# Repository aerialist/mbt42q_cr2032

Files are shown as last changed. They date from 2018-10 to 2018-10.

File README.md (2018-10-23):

# MDBT42Q BLE module breakout board

This is a breakout board for MDBT42Q module, a nRF52 based BLE.
https://www.seeedstudio.com/MDBT42Q-nRF52832-based-BLE-module-p-2736.html
http://www.raytac.com/product/ins.php?index_id=31

Schematics is largely copied from and inspired by Adafruit Feather nRF52 Bluefruit LE
https://www.adafruit.com/product/3406
https://learn.adafruit.com/bluefruit-nrf52-feather-learning-guide/introduction

and Redbear BLE Nano v2
https://redbear.cc/product/ble/ble-nano-2-soldered.html
https://github.com/redbear/nRF5x/tree/master/nRF52832

so that Arduino BSP developed by Adafruit or Redbear could be used as well as SDK from Nordic.
(Personally I'd recommend to go with Adafruit now that Redbear joined Particle)

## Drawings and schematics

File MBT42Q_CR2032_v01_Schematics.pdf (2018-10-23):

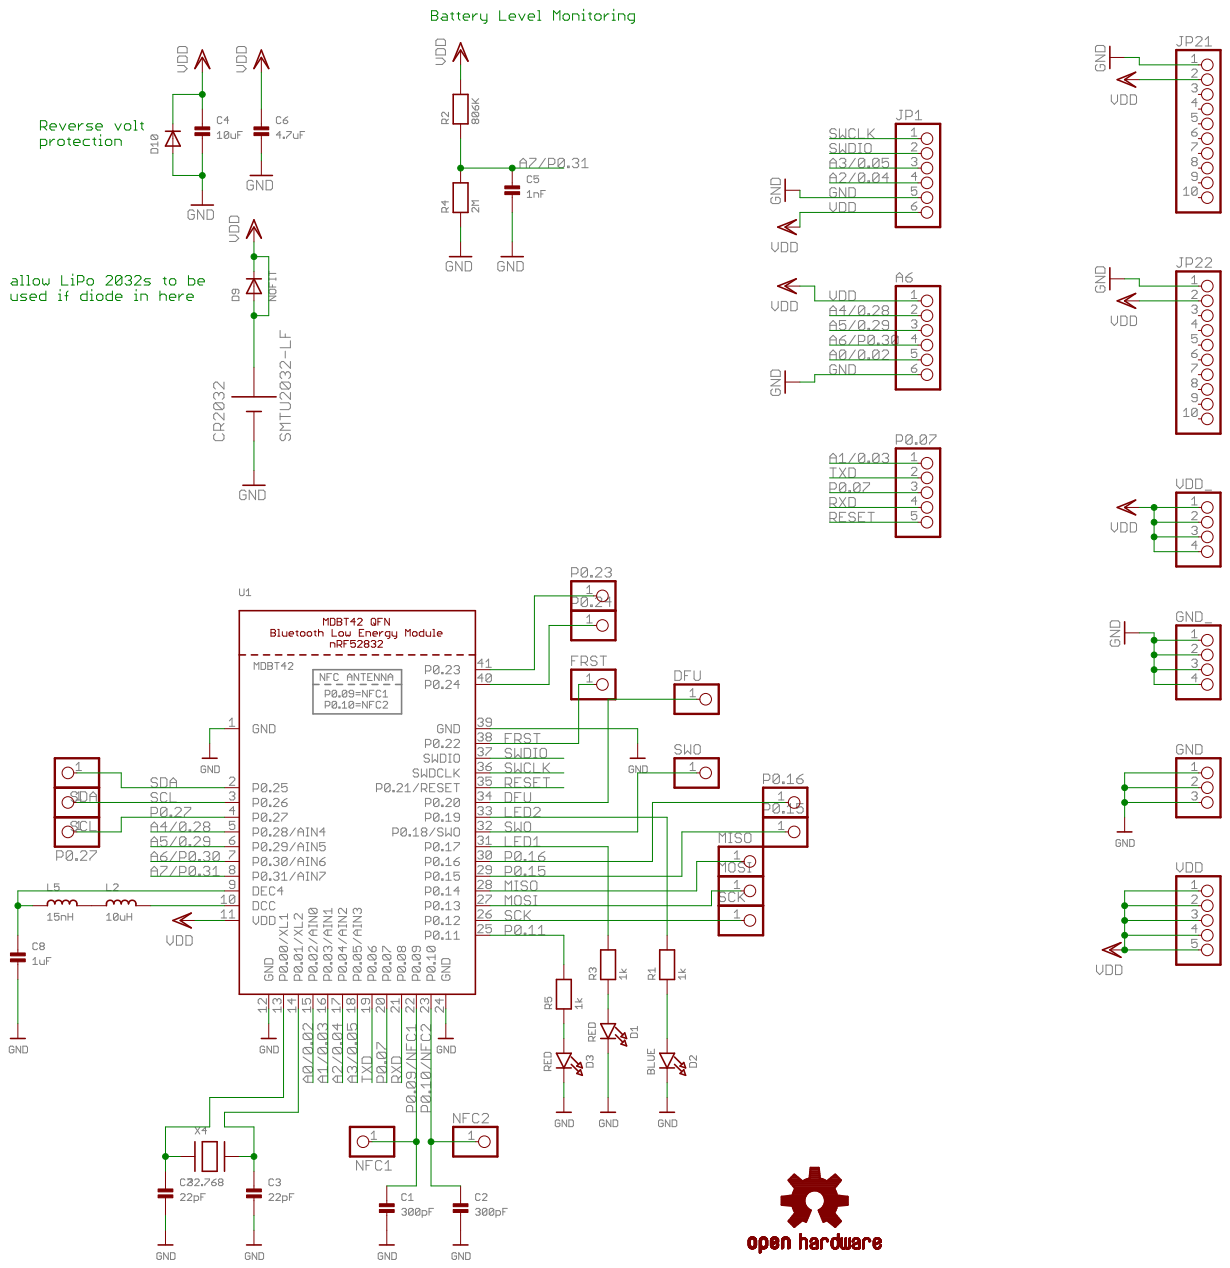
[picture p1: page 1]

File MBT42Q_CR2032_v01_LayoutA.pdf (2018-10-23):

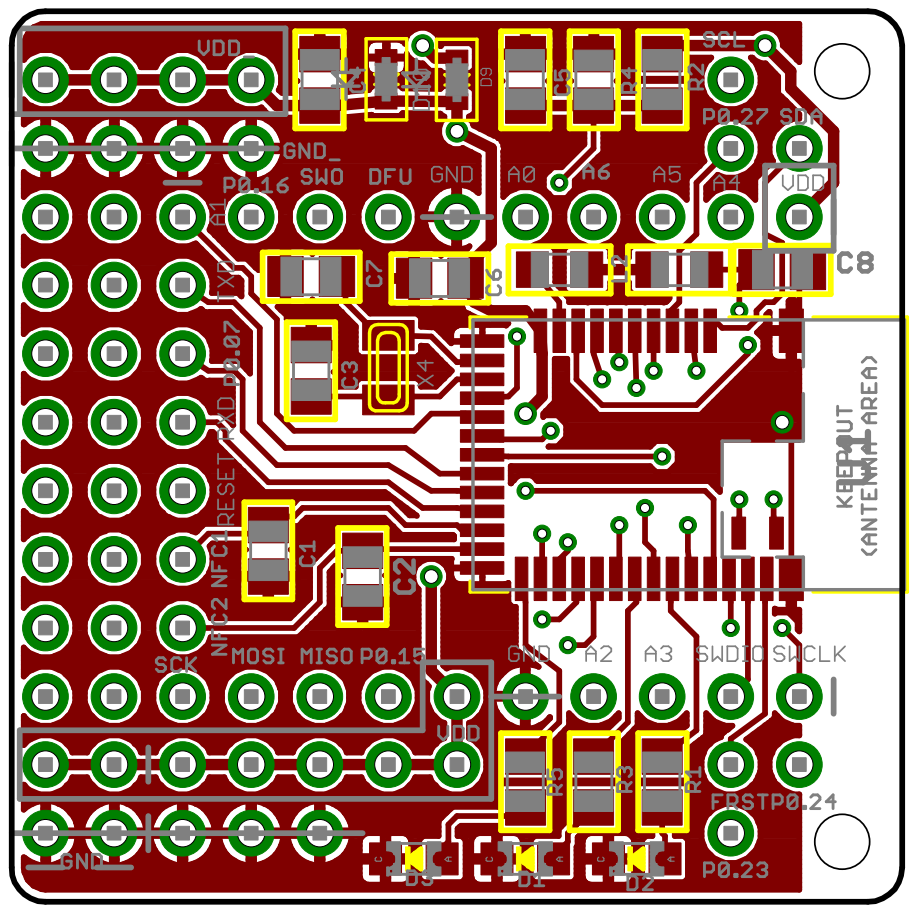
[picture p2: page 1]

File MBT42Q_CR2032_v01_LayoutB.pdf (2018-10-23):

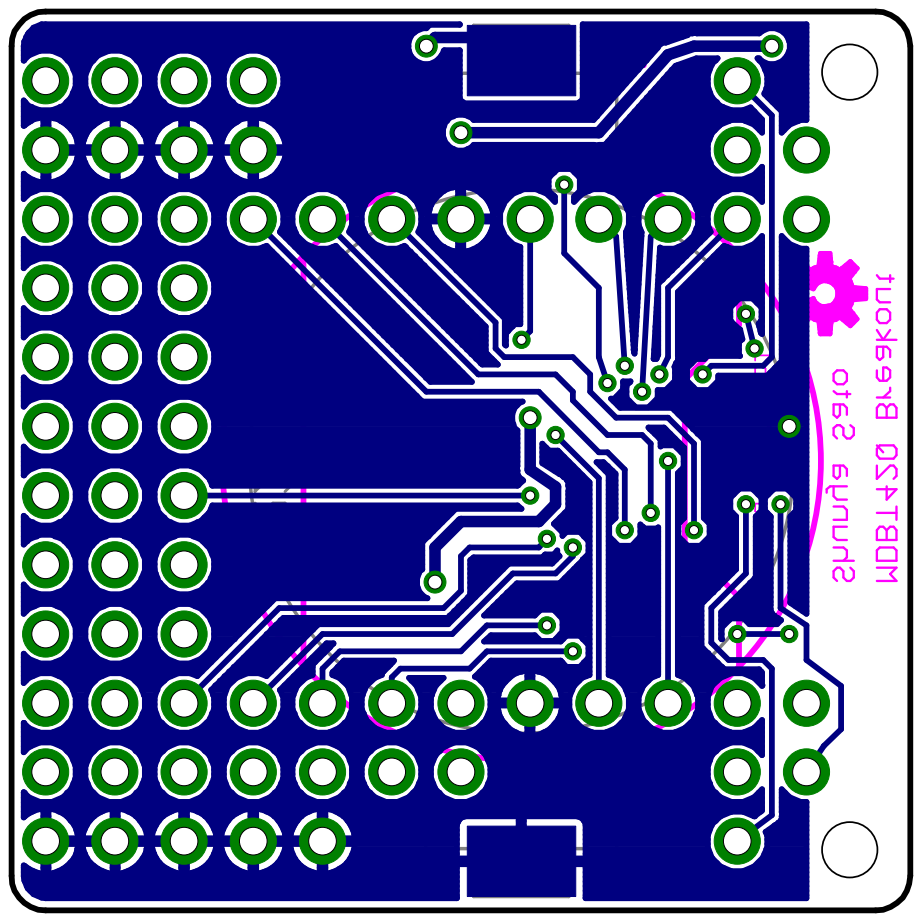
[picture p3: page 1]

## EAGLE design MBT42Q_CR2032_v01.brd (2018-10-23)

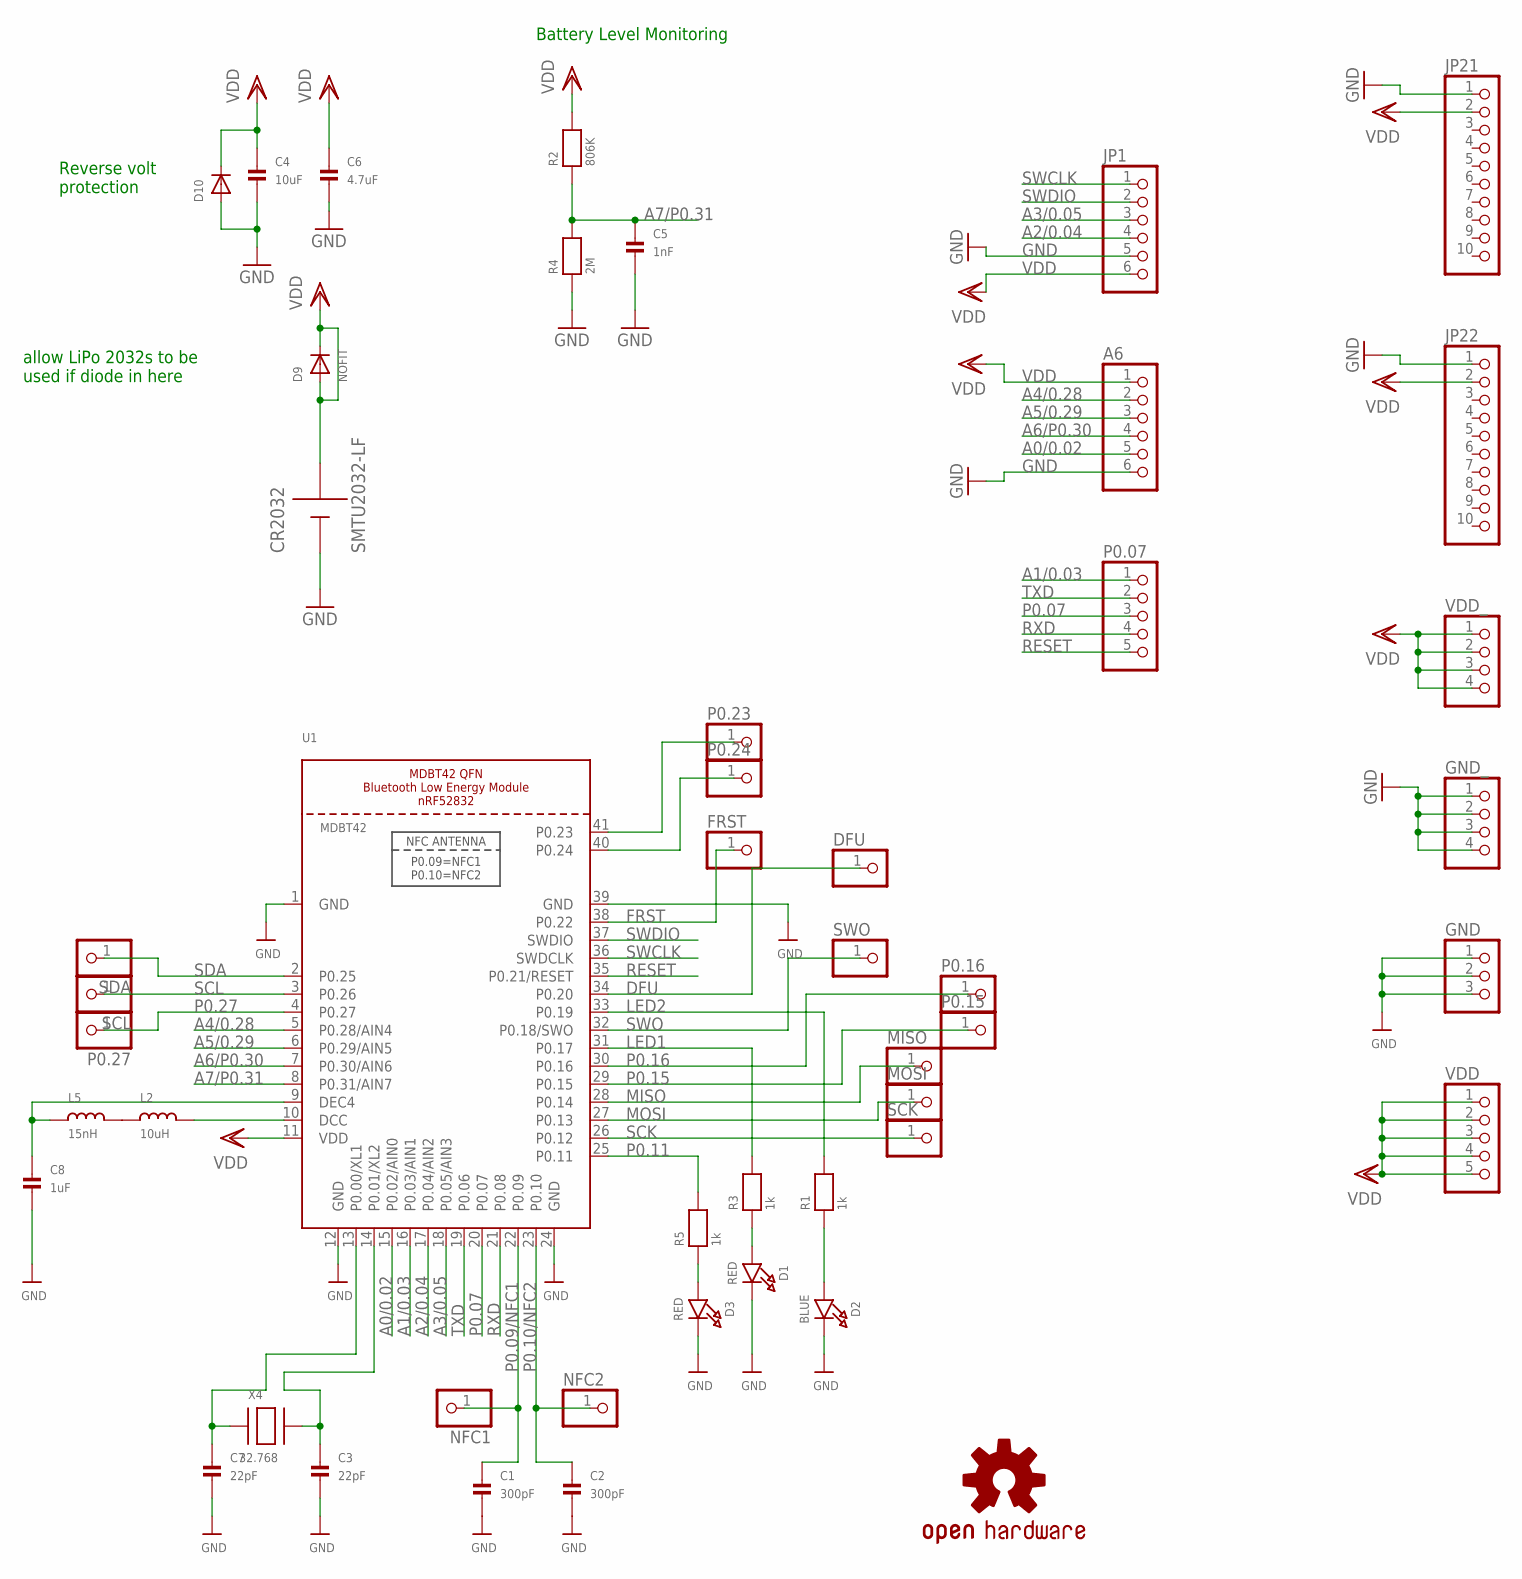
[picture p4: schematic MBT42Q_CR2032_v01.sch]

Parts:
A6: HEADER-1X6ROUND; 1X06_ROUND
C1, C2: 300pF; 0805
C3, C7: 22pF; 0805
C4: 10uF; 0805
C5: 1nF; 0805
C6: 4.7uF; 0805
C8: 1uF; 0805
CR2032: SMTU2032-LF
D1, D3: RED; CHIPLED_0805_NOOUTLINE
D2: BLUE; CHIPLED_0805_NOOUTLINE
D9: NOFIT; SOD-523
D10: DIODESOD-523; SOD-523
DFU: HEADER-1X1ROUND; 1X01_ROUND
FRST: HEADER-1X1ROUND; 1X01_ROUND
GND: HEADER-1X3ROUND; 1X03_ROUND
GND_: HEADER-1X4ROUND; 1X04_ROUND
JP1: HEADER-1X6ROUND; 1X06_ROUND
JP21, JP22: HEADER-1X10ROUND; 1X10_ROUND
L2: 10uH; _0805
L5: 15nH; _0805
LOGO1: OSHW-LOGOS; OSHW-LOGO-S
MISO: HEADER-1X1ROUND; 1X01_ROUND
MOSI: HEADER-1X1ROUND; 1X01_ROUND
NFC1, NFC2: HEADER-1X1ROUND; 1X01_ROUND
P0.07: HEADER-1X5ROUND; 1X05_ROUND
P0.15, P0.16, P0.23, P0.24, P0.27: HEADER-1X1ROUND; 1X01_ROUND
R1, R3, R5: 1k; 0805
R2: 806K; 0805
R4: 2M; 0805
SCK: HEADER-1X1ROUND; 1X01_ROUND
SCL: HEADER-1X1ROUND; 1X01_ROUND
SDA: HEADER-1X1ROUND; 1X01_ROUND
SWO: HEADER-1X1ROUND; 1X01_ROUND
U1: MDBT42; BLE_MODULE_RAYTAC_MDBT42
VDD: HEADER-1X5ROUND; 1X05_ROUND
VDD_: HEADER-1X4ROUND; 1X04_ROUND
X4: 32.768; XTAL3215

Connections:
A0/0.02: A6.5, U1.15 (P0.02/AIN0)
A1/0.03: P0.07.1, U1.16 (P0.03/AIN1)
A2/0.04: JP1.4, U1.17 (P0.04/AIN2)
A3/0.05: JP1.3, U1.18 (P0.05/AIN3)
A4/0.28: A6.2, U1.5 (P0.28/AIN4)
A5/0.29: A6.3, U1.6 (P0.29/AIN5)
A6/P0.30: A6.4, U1.7 (P0.30/AIN6)
A7/P0.31: C5.1, R2.1, R4.2, U1.8 (P0.31/AIN7)
DFU: DFU.1, U1.34 (P0.20)
FRST: FRST.1, U1.38 (P0.22)
GND: A6.6, C1.2, C2.2, C3.2, C4.2, C5.2, C6.2, C7.2, C8.2, CR2032.P$2 (GND), D1.C, D2.C, D3.C, D10.A, GND.1, GND.2, GND.3, GND_.1, GND_.2, GND_.3, GND_.4, JP1.5, JP21.1, JP22.1, R4.1, U1.1 (GND), U1.12 (GND), U1.24 (GND), U1.39 (GND)
LED1: R3.2, U1.31 (P0.17)
LED2: R1.2, U1.33 (P0.19)
MISO: MISO.1, U1.28 (P0.14)
MOSI: MOSI.1, U1.27 (P0.13)
unnamed: C7.1, U1.13 (P0.00/XL1), X4.P$1
unnamed: C3.1, U1.14 (P0.01/XL2), X4.P$2
unnamed: L2.2, U1.10 (DCC)
unnamed: L2.1, L5.2
unnamed: D1.A, R3.1
unnamed: D3.A, R5.1
unnamed: D2.A, R1.1
unnamed: C8.1, L5.1, U1.9 (DEC4)
unnamed: P0.24.1, U1.40 (P0.24)
unnamed: P0.23.1, U1.41 (P0.23)
P0.07: P0.07.3, U1.20 (P0.07)
P0.09/NFC1: C1.1, NFC1.1, U1.22 (P0.09)
P0.10/NFC2: C2.1, NFC2.1, U1.23 (P0.10)
P0.11: R5.2, U1.25 (P0.11)
P0.15: P0.15.1, U1.29 (P0.15)
P0.16: P0.16.1, U1.30 (P0.16)
P0.27: P0.27.1, U1.4 (P0.27)
RESET: P0.07.5, U1.35 (P0.21/RESET)
RXD: P0.07.4, U1.21 (P0.08)
SCK: SCK.1, U1.26 (P0.12)
SCL: SCL.1, U1.3 (P0.26)
SDA: SDA.1, U1.2 (P0.25)
SWCLK: JP1.1, U1.36 (SWDCLK)
SWDIO: JP1.2, U1.37 (SWDIO)
SWO: SWO.1, U1.32 (P0.18/SWO)
TXD: P0.07.2, U1.19 (P0.06)
VDD: A6.1, C4.1, C6.1, CR2032.P$1 (3V), D9.A, D9.K (C), D10.K (C), JP1.6, JP21.2, JP22.2, R2.2, U1.11 (VDD), VDD.1, VDD.2, VDD.3, VDD.4, VDD.5, VDD_.1, VDD_.2, VDD_.3, VDD_.4

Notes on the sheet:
allow LiPo 2032s to be used if diode in here
Reverse volt protection
Battery Level Monitoring

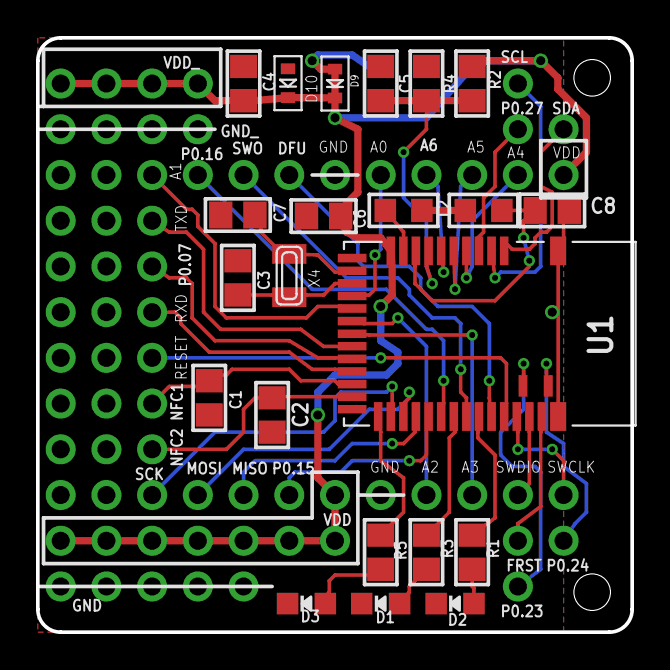
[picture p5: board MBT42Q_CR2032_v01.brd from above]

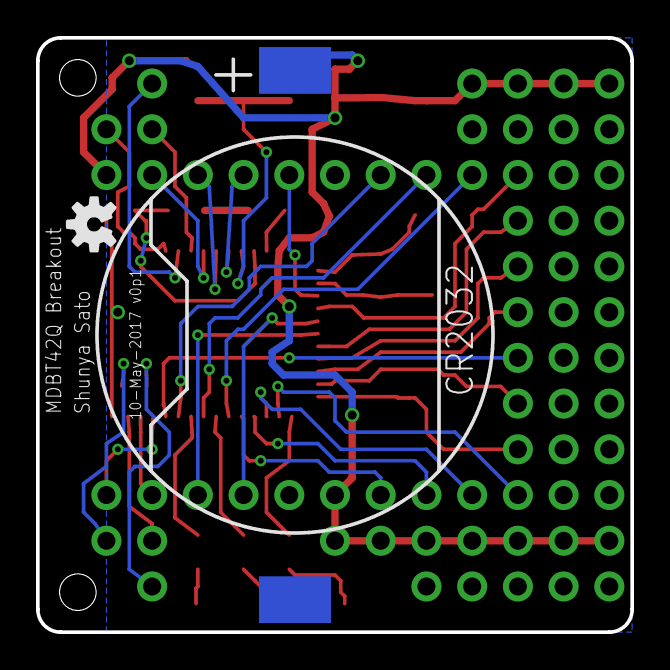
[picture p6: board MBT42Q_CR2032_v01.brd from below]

Board: 2 copper layers, 33.0 x 33.0 mm, 48 parts (2 on the bottom side), 42 nets.

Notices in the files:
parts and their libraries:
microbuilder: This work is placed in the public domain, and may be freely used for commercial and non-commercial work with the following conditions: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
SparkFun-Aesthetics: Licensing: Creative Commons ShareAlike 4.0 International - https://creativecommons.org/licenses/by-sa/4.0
